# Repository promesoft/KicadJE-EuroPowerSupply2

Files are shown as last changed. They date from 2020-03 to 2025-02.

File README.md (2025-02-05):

# KicadJE-EuroPowerSupply2
4HP PSU faceplate with 80x100mm PSU + PDU board. Faceplate input from a laptop PSU (19V) and may be daisychained to the next Eurorack unit.

Please note this method of making +- 12v could be impaired by the laptop PSU ground connection. Some PSU's connect earth to GND (sleeve) which will be connected to -12v and not GND in this circuit. If the laptop PSU only has 2 pins or the 3rd pin is not connected to the sleeve of 19v supply there will be no issues with this design.

There is a third version that does not rely on a laptop supply in the making (2025 Q1)

# Vital Components

# Status - mounted in rack
## Initial 
| Stage  | Detail | Status |
| --- | --- | --- |
| create material  | sch | done |
| | pcb | done |
| | gerber | done |
| production  | | done |
|  | produced | done |
|  | delivered | done |
## Preliminary validation
| Test  | Detail | Status |
| --- | --- | --- |
| Initial Inspection | | good alignment w panel - panel: pwr holes 2 mm too small |
| Initial Technical Test |  | OL LED's lighting up without load - probably due to the extra resistance of the polyfuse |
| Initial Technical Test |  | OL LED's ok with 2k2 but unsure of how they work now - 3k9 is ok without load but makes a bit of a light at a few XX mA |
| Initial Technical Test |  | input fuse experienced a few problems after shoring the input of the DC-DC by mistake
| Initial Product Test |  | ok - Powers the uP DAC nicely|

## Secondary validation
| Test  | Detail | Status |
| --- | --- |--- |
| Product Test |  | |
| Product Test |  | |
| Quality |  | |
| Quality | | |
| Long Term Product Test |  | Working for a year without stability issues | 
|  | | Bridge recitifier gets warm/hot |
| Power Draw | up to 750mA 19V | 

## Errata
### Errata - 
Holes for Pwr in and out are 2mm too small in face plate

Place DCDC input further away from electronics on the backside - risky location

## Issues and Notes
### Front
There is just enough room on the front PCB to add a JST header for power feed to baseboard.

### Regulation
Input cap C101 = 470uF/50V

Reg input cap C207 - 470uF/16V for 5V

Reg input cap C204 C212 - 100uF/35V for +-12V

Reg output cap C206 C209 C214 - 470uF/16V for all

### Output
Only half the headers has decoupling caps

Place +/-15v header away from heatsink area.

### Overload Circuit
Not easy to measure the OL circuit as it is VERY close to the DC-DC input  
Add current limiter on input and consider changing from OL to currentlimier with limit indication  
OL LED's ok with 2k2 but unsure of how they work now - 3k9 is ok without load but makes a bit of a light at a few XX mA  

### Extensions
Consider calc initial regulator stage as Capacitor multiplier and add small signal BJT in darlington config.
 - https://www.google.com/search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

# Pictures
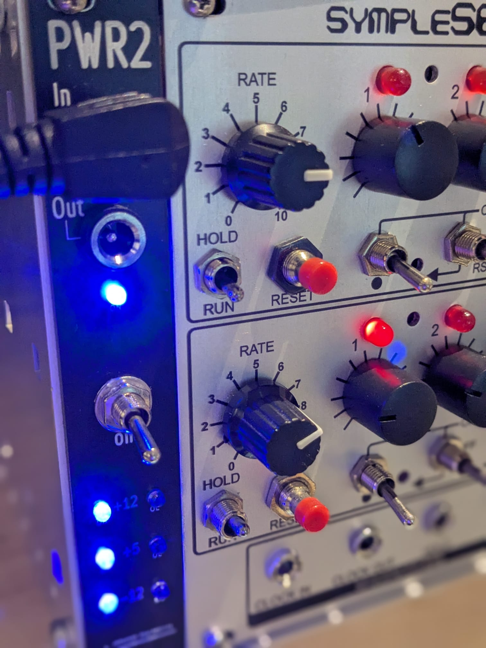
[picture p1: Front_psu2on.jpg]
Front Picture

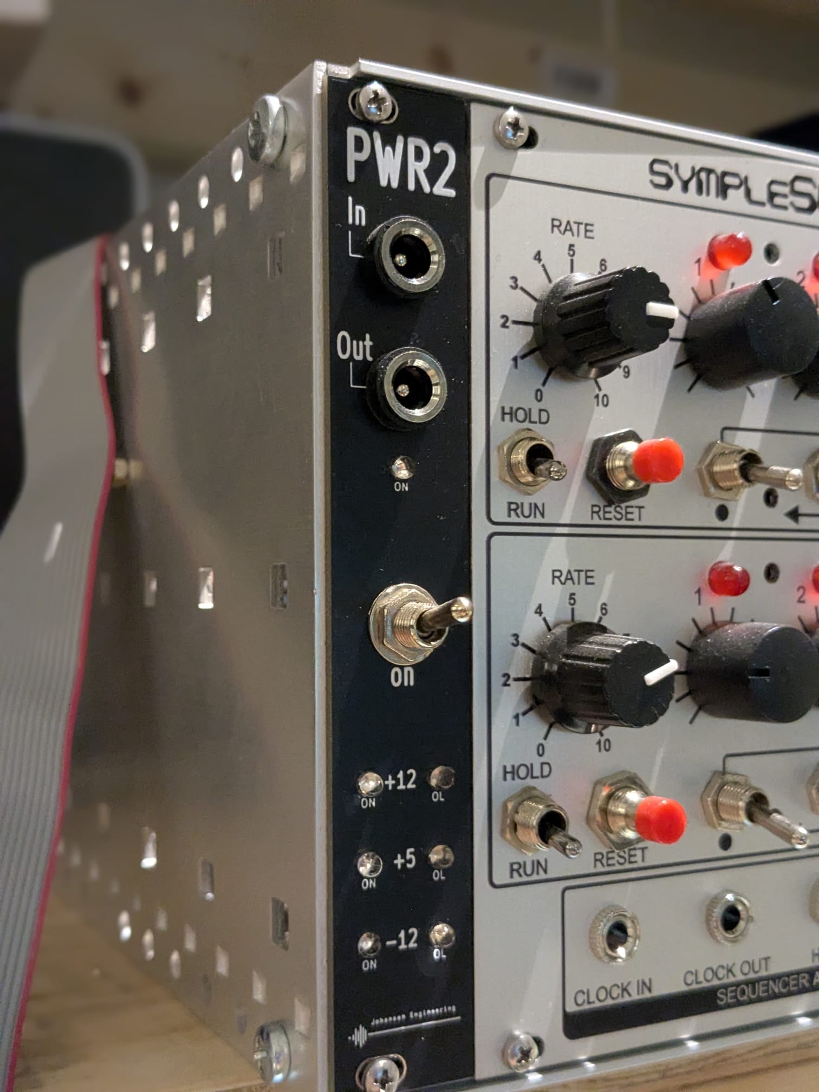
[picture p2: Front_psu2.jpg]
Front Picture

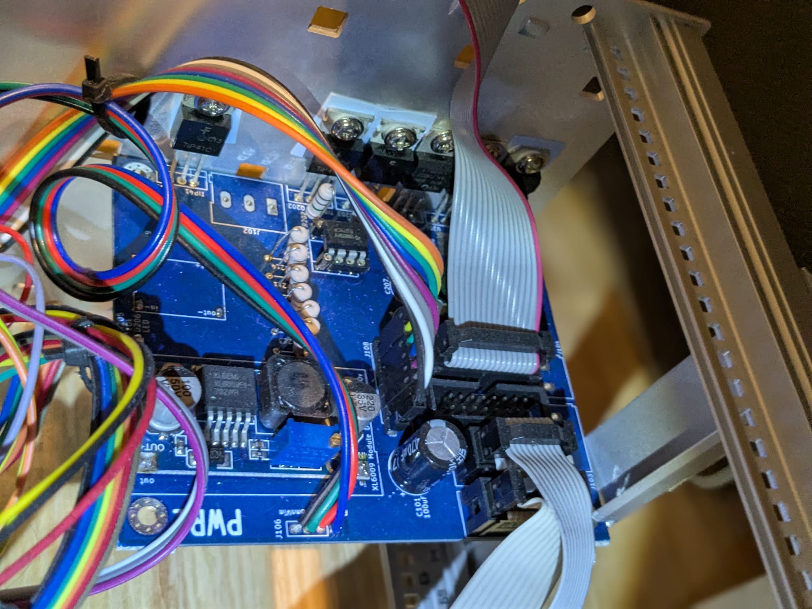
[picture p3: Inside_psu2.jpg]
Inside Picture

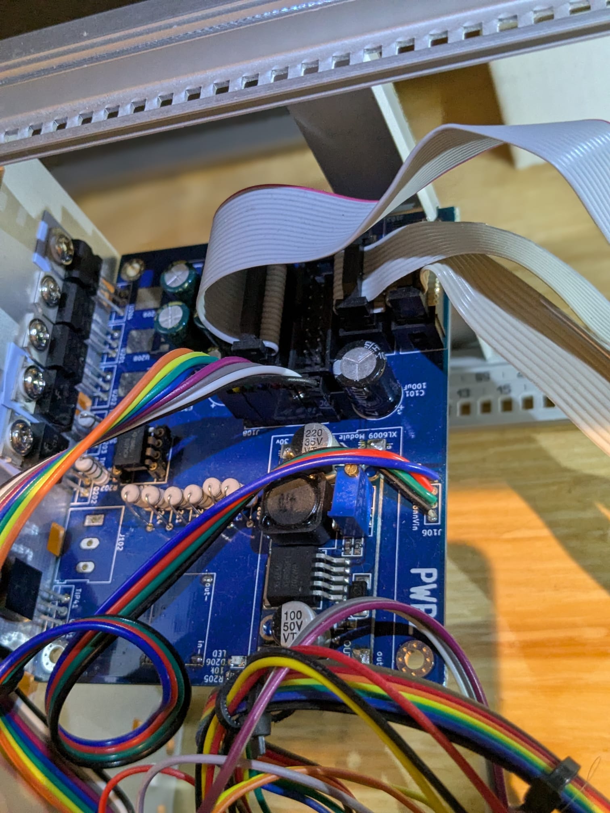
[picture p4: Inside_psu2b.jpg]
Inside Picture

## Rendered
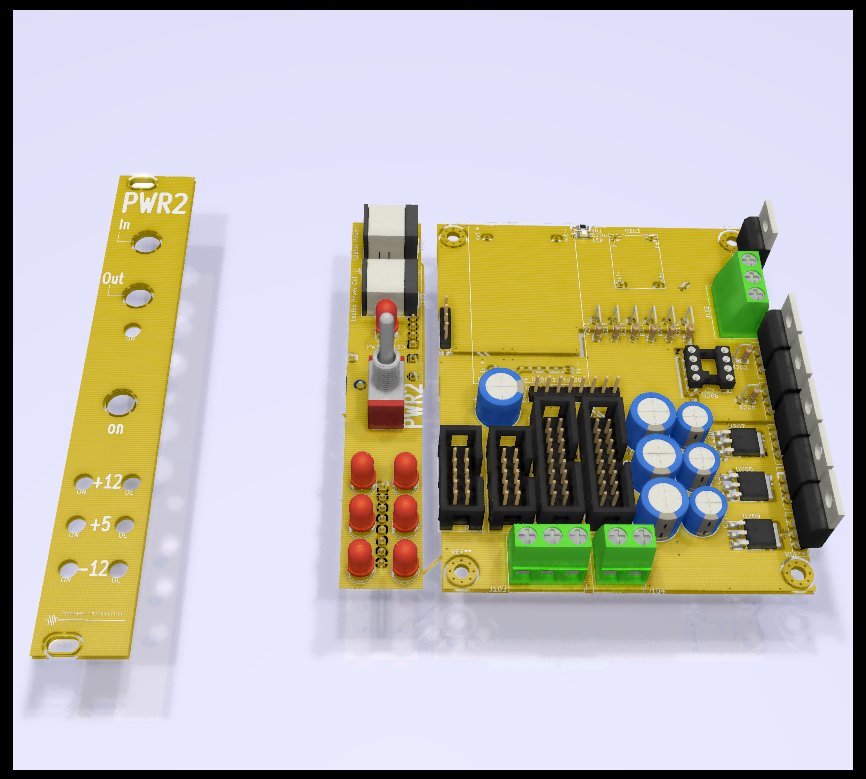
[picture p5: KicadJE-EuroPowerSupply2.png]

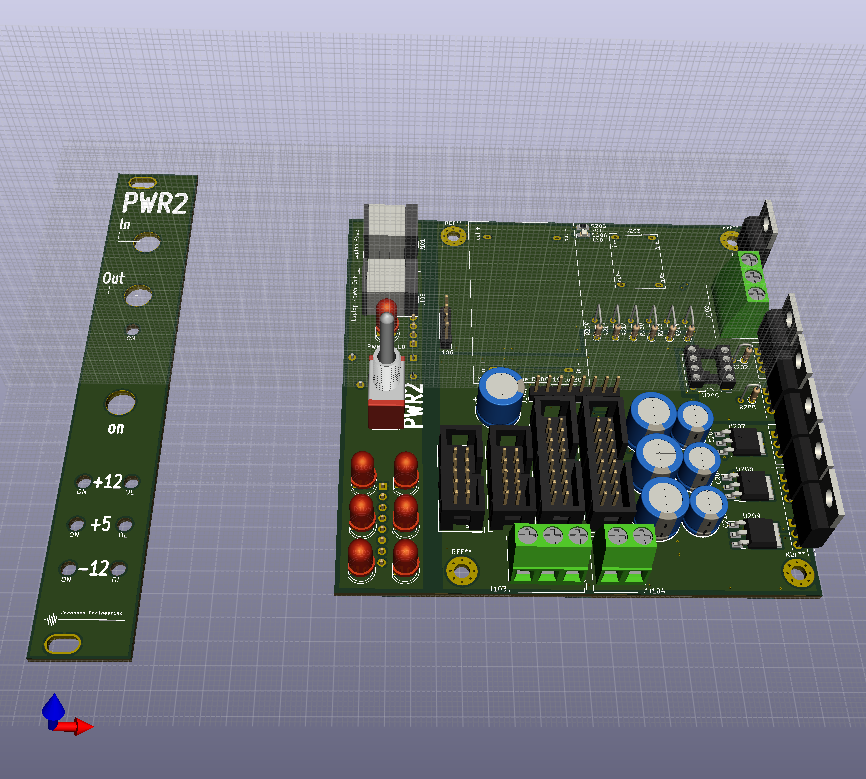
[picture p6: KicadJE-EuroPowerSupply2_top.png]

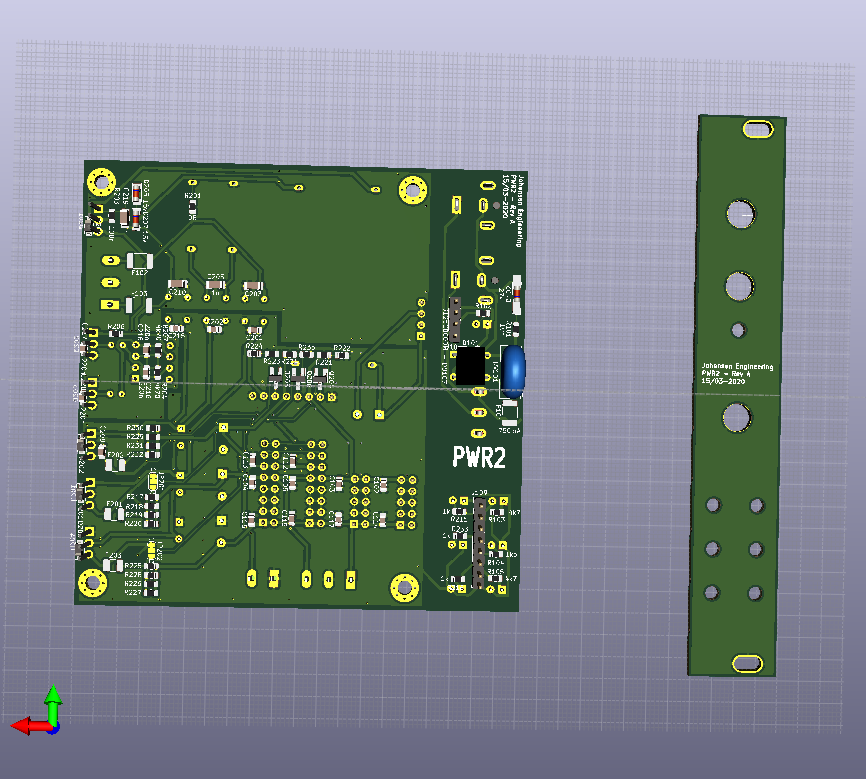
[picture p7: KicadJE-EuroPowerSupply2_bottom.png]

# Schematic
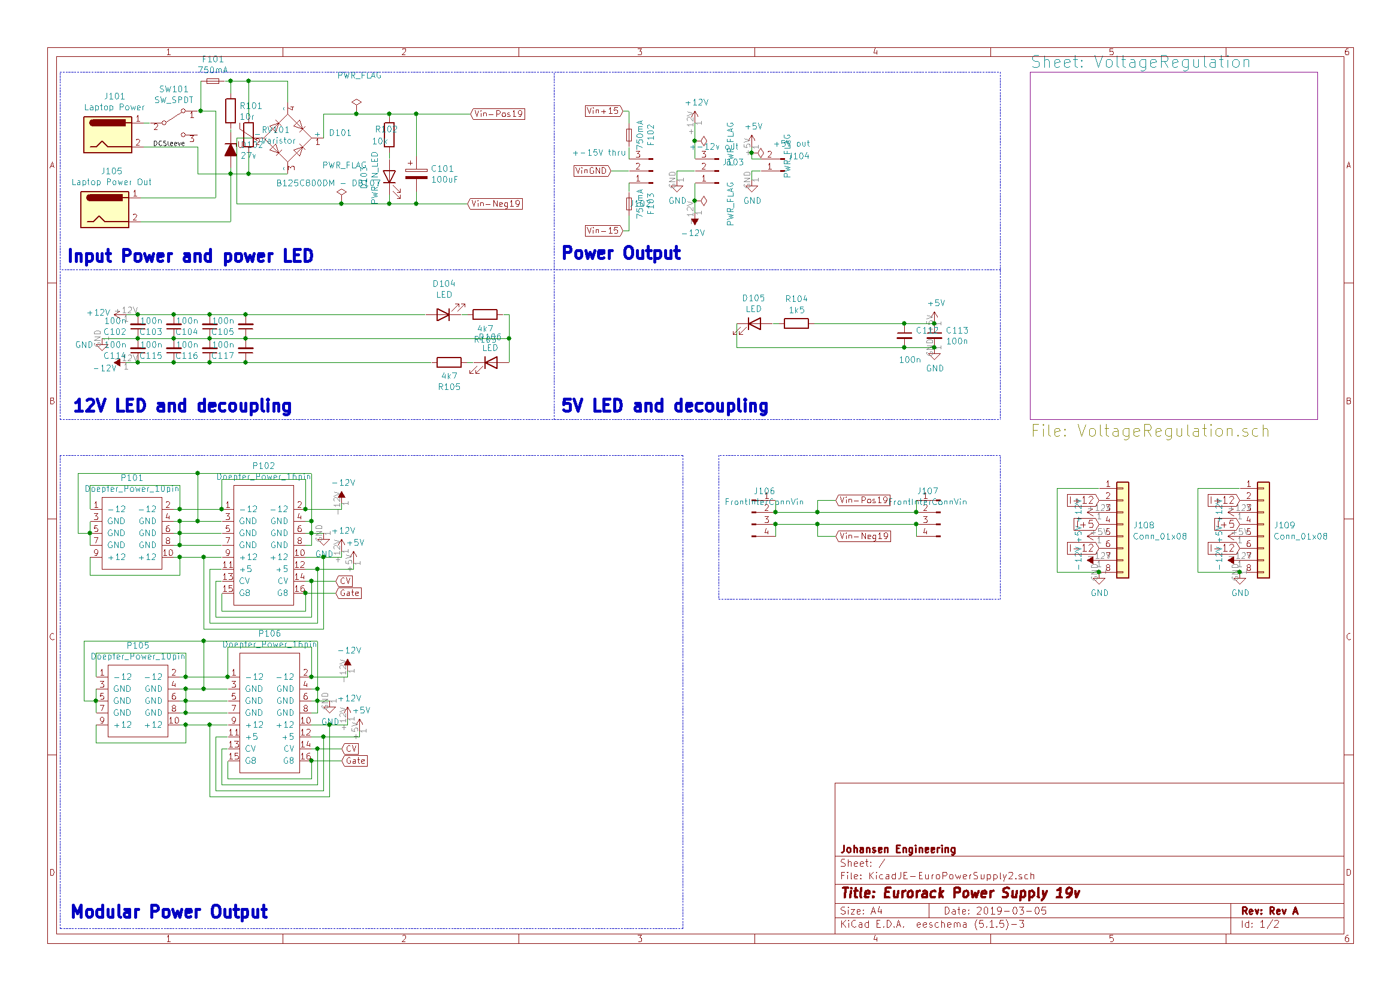
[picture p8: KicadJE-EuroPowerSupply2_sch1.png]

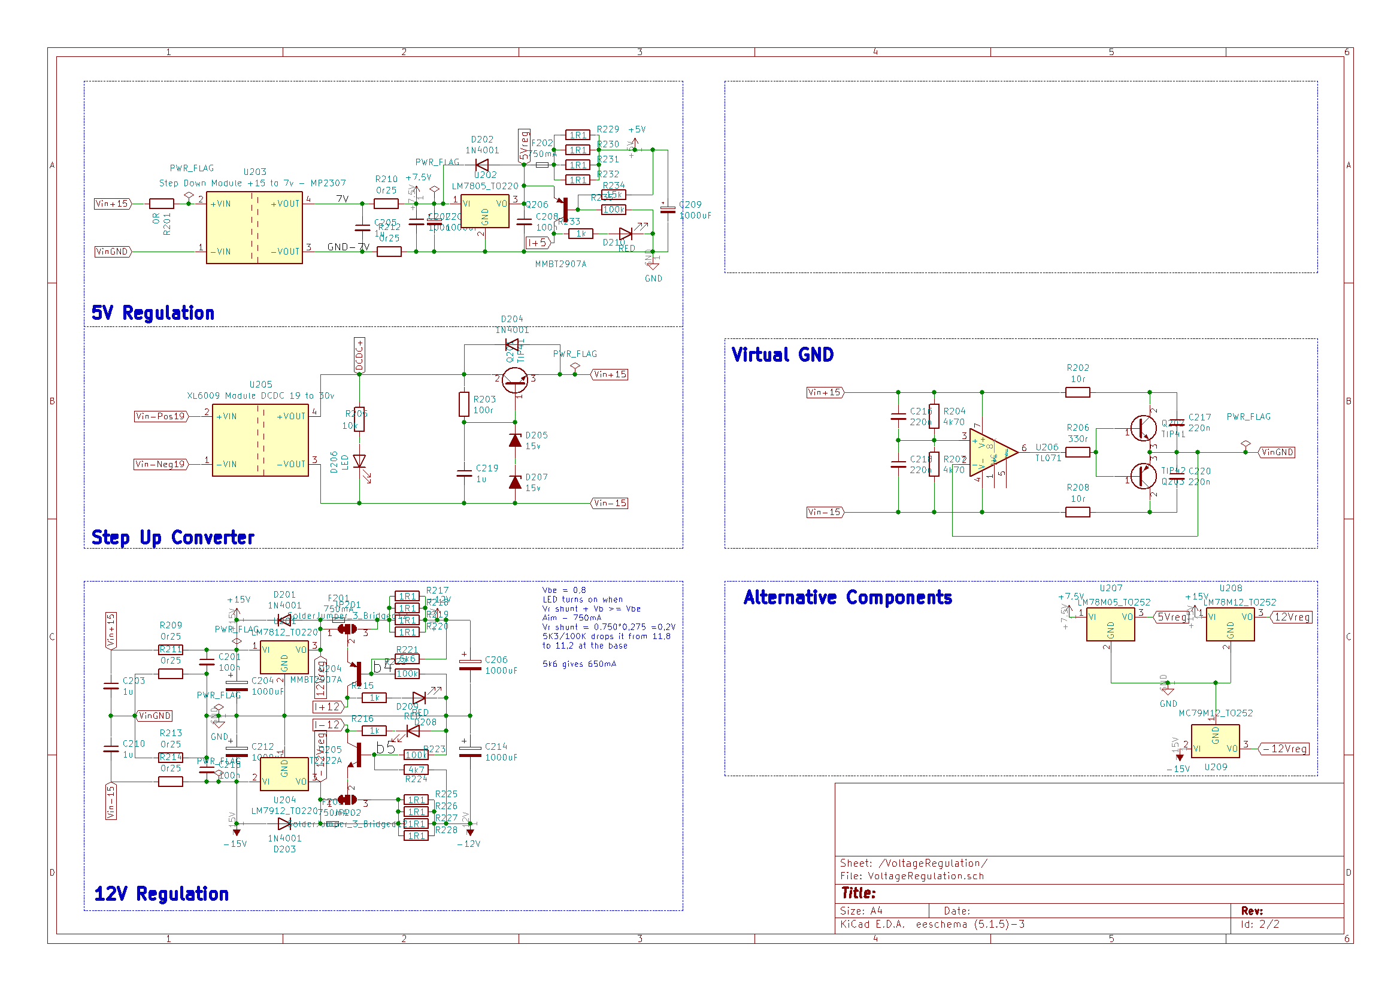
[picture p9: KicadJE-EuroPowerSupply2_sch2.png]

## Prototype

# Inspiration
## Rev 1
https://github.com/promesoft/KicadJE-EuroPowerSupply

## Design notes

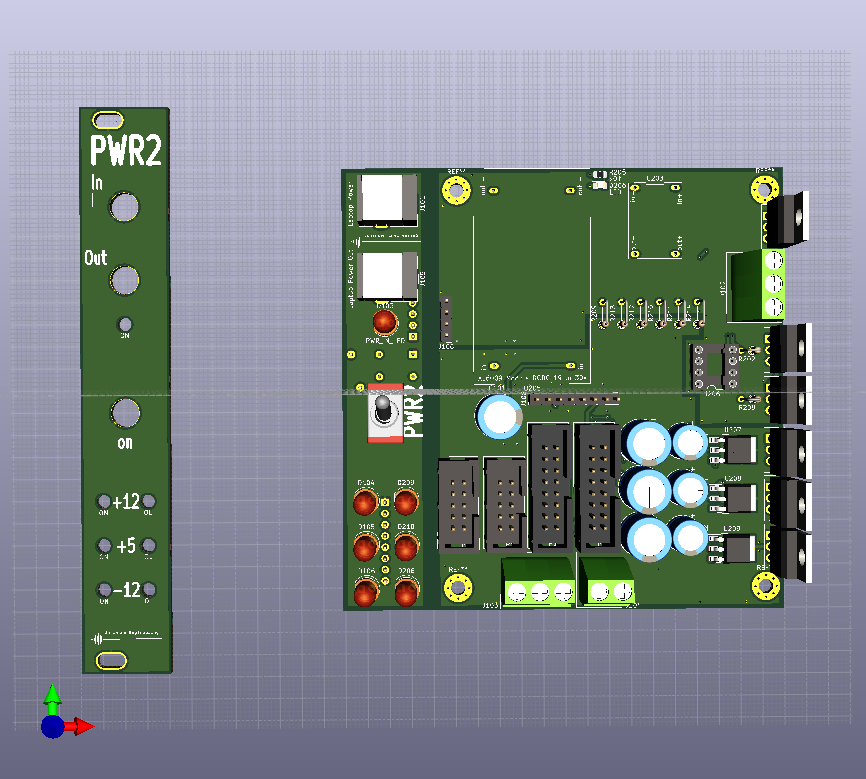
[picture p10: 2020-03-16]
KicadJE-EuroPowerSupply2_top2.png

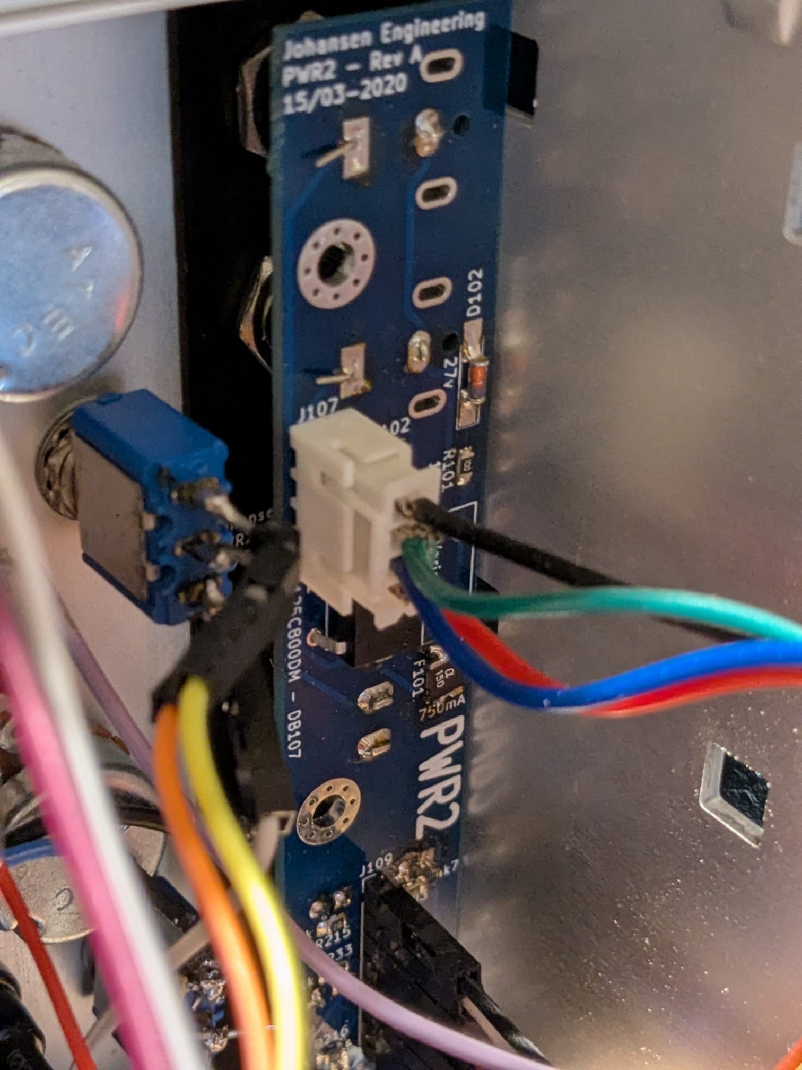
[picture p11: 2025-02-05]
Front_psu2on_back.jpg

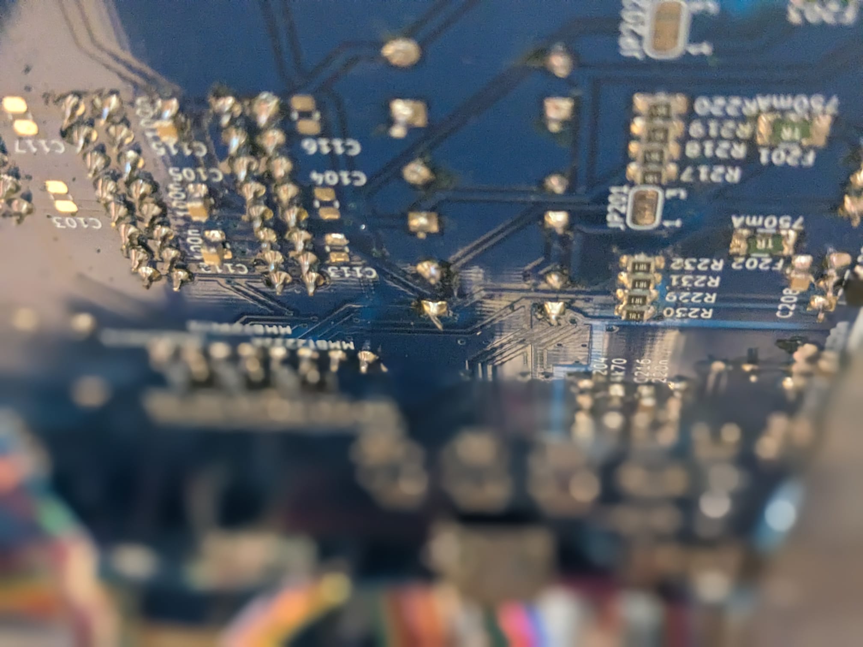
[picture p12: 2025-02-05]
Inside_psu2_bottom.jpg

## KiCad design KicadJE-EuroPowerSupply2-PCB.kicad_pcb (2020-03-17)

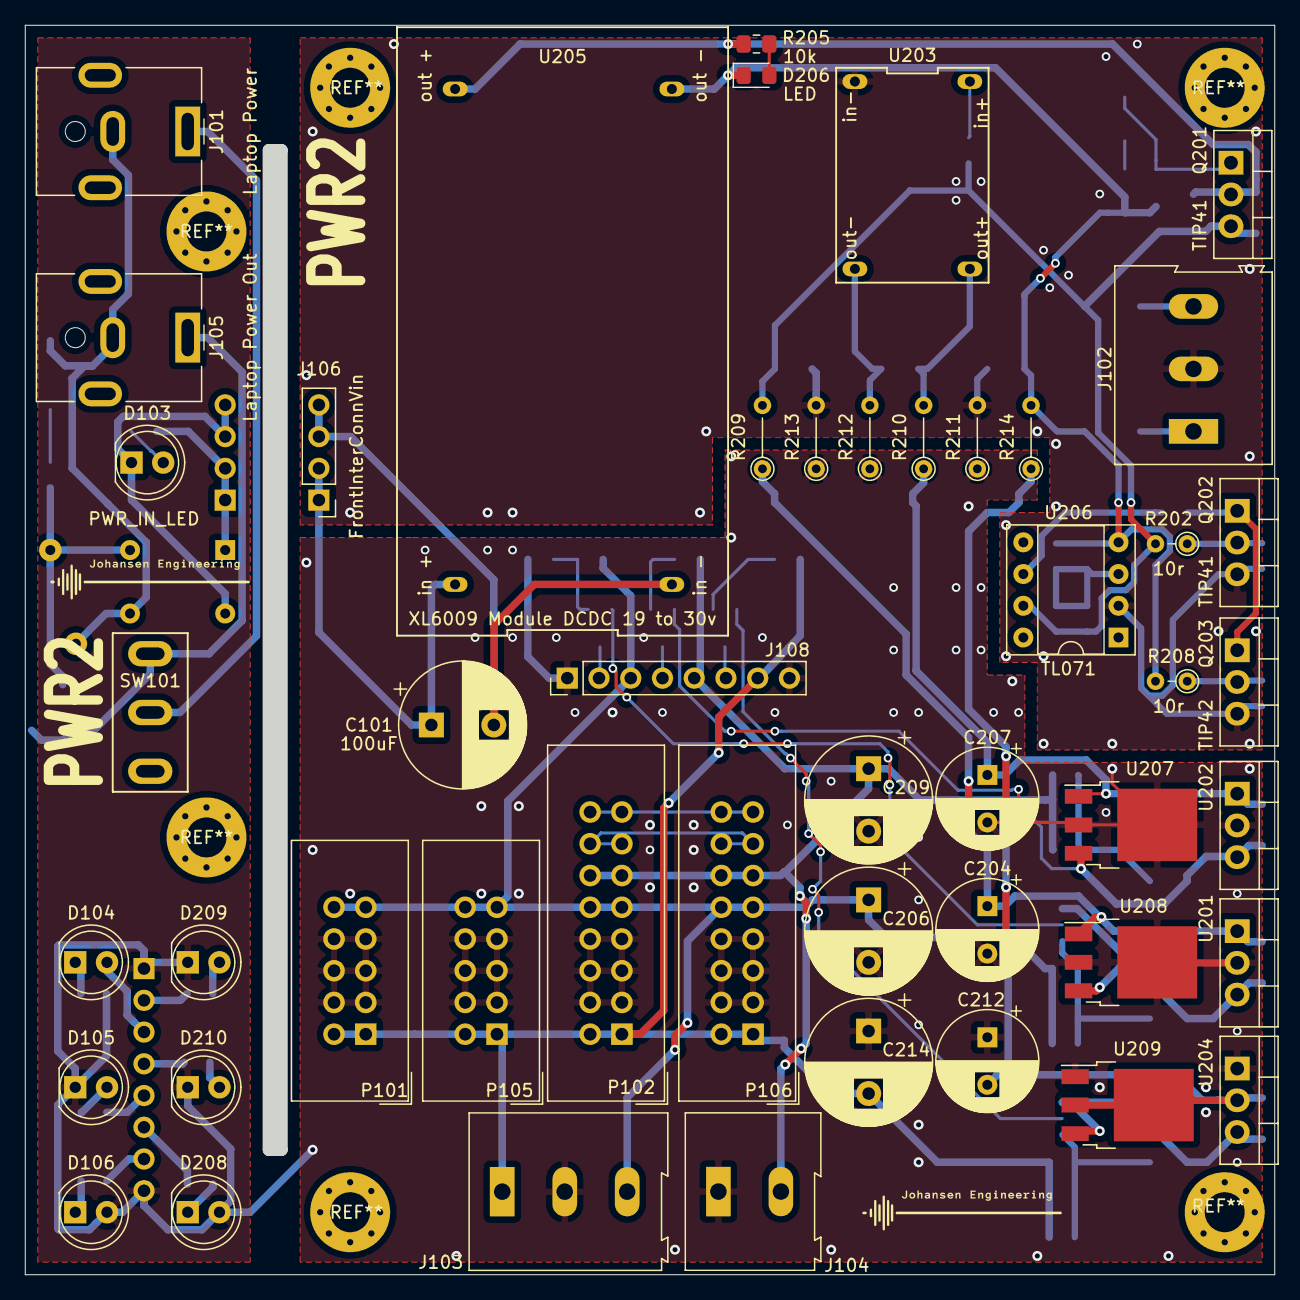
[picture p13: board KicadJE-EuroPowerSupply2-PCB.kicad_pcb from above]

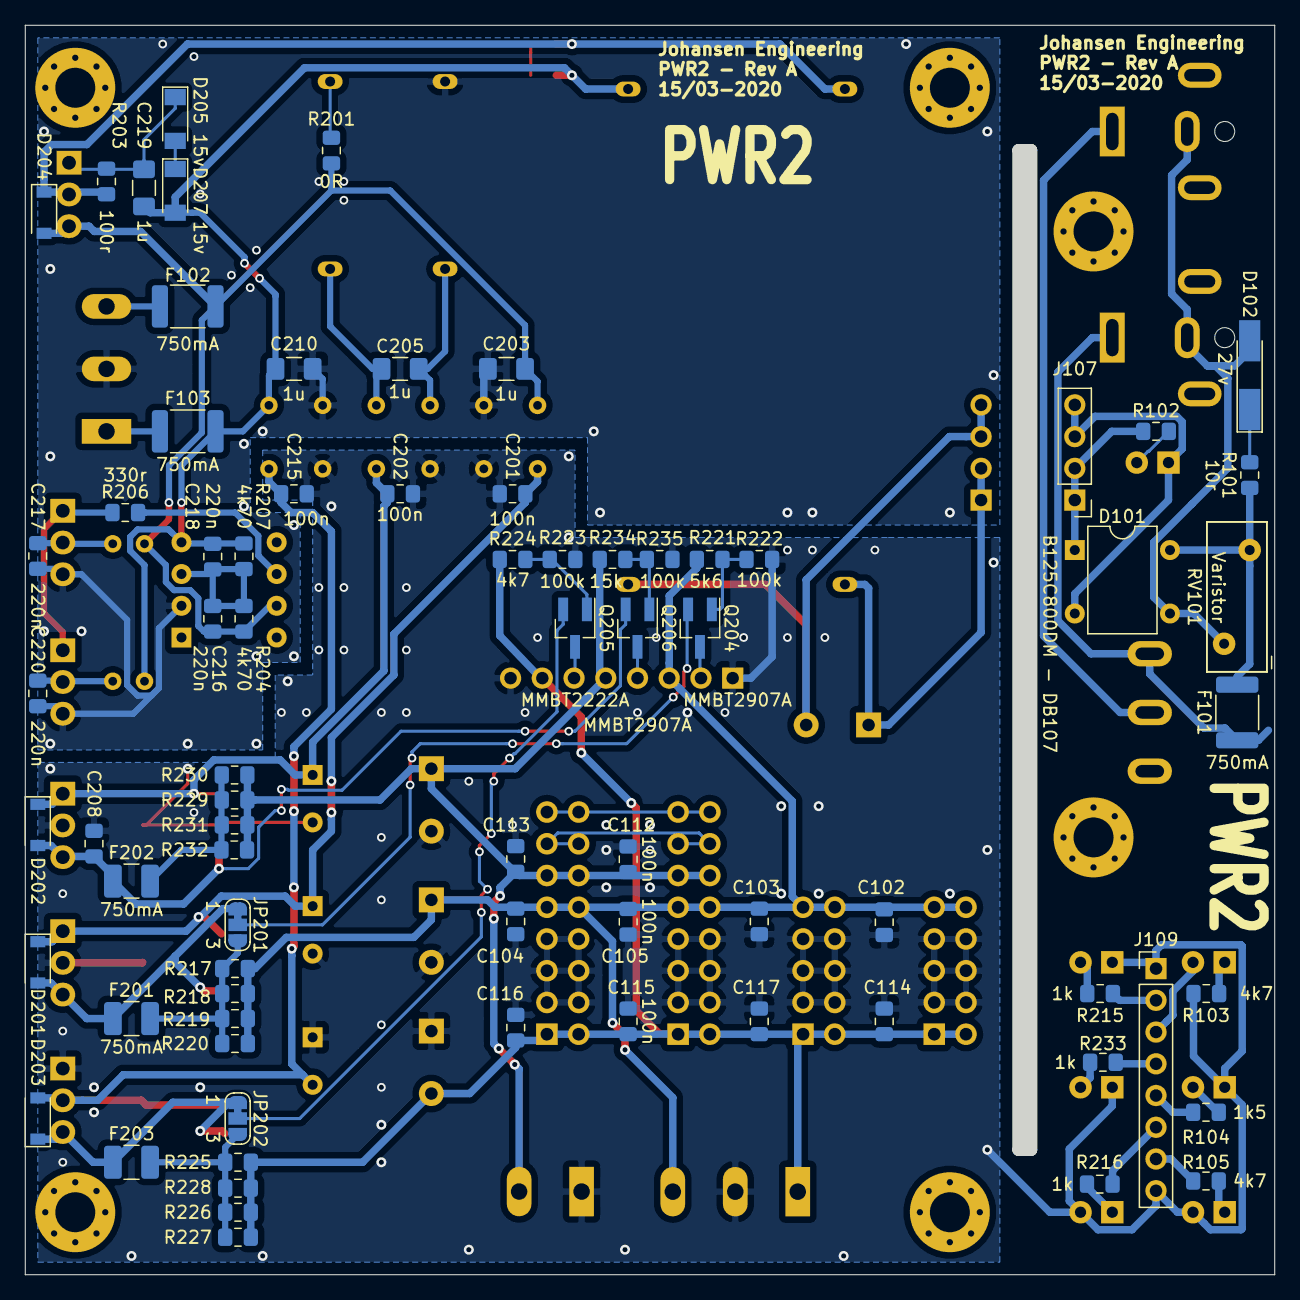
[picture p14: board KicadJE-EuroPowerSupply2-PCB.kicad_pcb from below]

Board: 2 copper layers, 100.0 x 100.0 mm, 123 parts (75 on the bottom side), 54 nets.

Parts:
C101: 100uF; CP_Radial_D10.0mm_P5.00mm
C102, C103, C104, C105, C112, C113, C114, C115, C116, C117, C201, C202, C208, C215: 100n; C_0805_2012Metric_Pad1.15x1.40mm_HandSolder
C203, C205, C210, C219: 1u; C_1206_3216Metric_Pad1.42x1.75mm_HandSolder
C204, C207, C212: 1000uF; CP_Radial_D8.0mm_P3.80mm
C206, C209, C214: 1000uF; CP_Radial_D10.0mm_P5.00mm
C216, C217, C218, C220: 220n; C_0805_2012Metric_Pad1.15x1.40mm_HandSolder
D101: B125C800DM - DB107; Diode_Bridge_DIP-4_W7.62mm_P5.08mm
D102: 27v; D_MiniMELF_Handsoldering
D103: PWR_IN_LED; LED_D5.0mm
D104, D105, D106: LED; LED_D5.0mm
D201, D202, D203, D204: 1N4001; D_SOD-123
D205, D207: 15v; D_MiniMELF
D206: LED; LED_0805_2012Metric_Pad1.15x1.40mm_HandSolder
D208, D209, D210: RED; LED_D5.0mm
F101, F102, F103: 750mA; Fuse_1812_4532Metric_Pad1.30x3.40mm_HandSolder
F201, F202, F203: 750mA; Fuse_1210_3225Metric_Pad1.42x2.65mm_HandSolder
J101: Laptop Power; BarrelJack_CUI_PJ-063AH_Horizontal
J102: +-15V thru; TerminalBlock_Altech_AK300-3_P5.00mm
J103: +-12v out; TerminalBlock_Altech_AK300-3_P5.00mm
J104: +5V out; TerminalBlock_Altech_AK300-2_P5.00mm
J105: Laptop Power Out; BarrelJack_CUI_PJ-063AH_Horizontal
J106, J107: FrontInterConnVin; PinHeader_1x04_P2.54mm_Vertical
J108, J109: Conn_01x08; PinHeader_1x08_P2.54mm_Vertical
JP201, JP202: SolderJumper_3_Bridged12; SolderJumper-3_P1.3mm_Bridged12_RoundedPad1.0x1.5mm_NumberL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
P101, P105: Doepfer_Power_10pin; IDC-Header_2x05_Pitch2.54mm_Straight
P102, P106: Doepfer_Power_16pin; IDC-Header_2x08_Pitch2.54mm_Straight
Q201, Q202: TIP41; TO-220-3_Vertical
Q203: TIP42; TO-220-3_Vertical
Q204, Q206: MMBT2907A; SOT-23_Handsoldering
Q205: MMBT2222A; SOT-23_Handsoldering
R101: 10r; R_0805_2012Metric_Pad1.15x1.40mm_HandSolder
R102, R205: 10k; R_0805_2012Metric_Pad1.15x1.40mm_HandSolder
R103, R105, R224: 4k7; R_0805_2012Metric_Pad1.15x1.40mm_HandSolder
R104: 1k5; R_0805_2012Metric_Pad1.15x1.40mm_HandSolder
R201: 0R; R_0805_2012Metric_Pad1.15x1.40mm_HandSolder
R202, R208: 10r; R_Axial_DIN0204_L3.6mm_D1.6mm_P2.54mm_Vertical
R203: 100r; R_0805_2012Metric_Pad1.15x1.40mm_HandSolder
R204, R207: 4k70; R_0805_2012Metric_Pad1.15x1.40mm_HandSolder
R206: 330r; R_0805_2012Metric_Pad1.15x1.40mm_HandSolder
R209, R210, R211, R212, R213, R214: 0r25; R_Axial_DIN0204_L3.6mm_D1.6mm_P5.08mm_Vertical
R215, R216, R233: 1k; R_0805_2012Metric_Pad1.15x1.40mm_HandSolder
R217, R218, R219, R220, R225, R226, R227, R228, R229, R230, R231, R232: 1R1; R_0805_2012Metric_Pad1.15x1.40mm_HandSolder
R221: 5k6; R_0805_2012Metric_Pad1.15x1.40mm_HandSolder
R222, R223, R235: 100k; R_0805_2012Metric_Pad1.15x1.40mm_HandSolder
R234: 15k; R_0805_2012Metric_Pad1.15x1.40mm_HandSolder
RV101: Varistor; RV_Disc_D12mm_W4.8mm_P7.5mm
SW101: SW_SPDT; SP1MS1
U201: LM7812_TO220; TO-220-3_Vertical
U202: LM7805_TO220; TO-220-3_Vertical
U203: Step Down Module +15 to 7v - MP2307; MP2307 DCDC module
U204: LM7912_TO220; TO-220-3_Vertical
U205: XL6009 Module DCDC 19 to 30v; XL6009-DCDC-Module
U206: TL071; DIP-8_W7.62mm_Socket
U207: LM78M05_TO252; TO-252-3_TabPin2
U208: LM78M12_TO252; TO-252-3_TabPin2
U209: MC79M12_TO252; TO-252-3_TabPin2

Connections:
5Vreg: C208.1, D202.2, F202.1, Q206.2, U202.3, U207.3
12Vreg: D201.2, F201.1, JP201.1, U201.3, U208.3
+5V: C112.1, C113.1, C209.1, J104.2, J108.5, J109.5, P102.11, P102.12, P106.11, P106.12, R104.1, R229.1, R230.1, R231.1, R232.1, R234.2
+7.5V: C202.1, C207.1, D202.1, R210.1, U202.1, U207.1
+12V: C102.2, C103.2, C104.2, C105.2, C206.1, D104.2, J103.3, J108.3, J109.3, P101.9, P101.10, P102.9, P102.10, P105.9, P105.10, P106.9, P106.10, R217.1, R218.1, R219.1, R220.1, R221.2
+15V: C201.1, C204.1, D201.1, R209.1, U201.1, U208.1
-12V: C114.1, C115.1, C116.1, C117.1, C214.2, J103.1, J108.7, J109.7, P101.1, P101.2, P102.1, P102.2, P105.1, P105.2, P106.1, P106.2, R105.1, R224.1, R225.1, R226.1, R227.1, R228.1
-12Vreg: D203.1, F203.1, JP202.1, U204.3, U209.3
-15V: C212.2, C215.2, D203.2, R214.1, U204.2, U209.2
/DCSleeve: D101.3, D102.2, J101.2, J105.2, RV101.2
/VoltageRegulation/7V: C205.1, R210.2, U203.4
/VoltageRegulation/GND-7V: C205.2, R212.2, U203.3
/VoltageRegulation/b4: Q204.1, R221.1, R222.1
/VoltageRegulation/b5: Q205.1, R223.2, R224.2
CV: P102.13, P102.14, P106.13, P106.14
DCDC+: D204.1, Q201.2, R203.1, R205.1, U205.4
GND: C102.1, C103.1, C104.1, C105.1, C112.2, C113.2, C114.2, C115.2, C116.2, C117.2, C201.2, C202.2, C204.2, C206.2, C207.2, C208.2, C209.2, C212.1, C214.1, C215.1, D105.1, D106.2, D208.2, D209.1, D210.1, J103.2, J104.1, J108.1, J108.8, J109.1, J109.8, P101.3, P101.4, P101.5, P101.6, P101.7, P101.8, P102.3, P102.4, P102.5, P102.6, P102.7, P102.8, P105.3, P105.4, P105.5, P105.6, P105.7, P105.8, P106.3, P106.4, P106.5, P106.6, P106.7, P106.8, R103.1, R211.1, R212.1, R213.1, R222.2, R223.1, R235.2, U201.2, U202.2, U204.1, U207.2, U208.2, U209.1
Gate: P102.15, P102.16, P106.15, P106.16
I+5: J108.4, J109.4, Q206.3, R233.1
I+12: J108.2, J109.2, Q204.3, R215.1
I-12: J108.6, J109.6, Q205.3, R216.1
unnamed: C216.2, C218.1, R204.2, R207.1, U206.3
unnamed: C217.1, Q202.2, R202.1
unnamed: C219.1, D205.1, Q201.1, R203.2
unnamed: C220.2, Q203.2, R208.1
unnamed: D101.4, F101.2, R101.1, RV101.1
unnamed: D102.1, R101.2
unnamed: D103.2, R102.2
unnamed: D104.1, R103.2
unnamed: D105.2, R104.2
unnamed: D106.1, R105.2
unnamed: D205.2, D207.1
unnamed: D206.2, R205.2
unnamed: D208.1, R216.2
unnamed: D209.2, R215.2
unnamed: D210.2, R233.2
unnamed: F101.1, J105.1, SW101.1
unnamed: F102.2, J102.3
unnamed: F103.1, J102.1
unnamed: F201.2, JP201.3, R217.2, R218.2, R219.2, R220.2
unnamed: F202.2, R229.2, R230.2, R231.2, R232.2
unnamed: F203.2, JP202.3, R225.2, R226.2, R227.2, R228.2
unnamed: J101.1, SW101.2
unnamed: JP201.2, Q204.2
unnamed: JP202.2, Q205.2
unnamed: Q202.1, Q203.1, R206.1
unnamed: Q206.1, R234.1, R235.1
unnamed: R201.1, U203.2
unnamed: R206.2, U206.6
Vin+15: C203.1, C216.1, D204.2, F102.1, Q201.3, R201.2, R202.2, R204.1, R209.2, U206.7
Vin-15: C210.2, C218.2, C219.2, D206.1, D207.2, F103.2, R207.2, R208.2, R214.2, U205.3, U206.4
Vin-Neg19: C101.2, D101.2, D103.1, J106.3, J106.4, J107.3, J107.4, U205.1
Vin-Pos19: C101.1, D101.1, J106.1, J106.2, J107.1, J107.2, R102.1, U205.2
VinGND: C203.2, C210.1, C217.2, C220.1, J102.2, Q202.3, Q203.3, R211.2, R213.2, U203.1, U206.2

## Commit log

2020-03-12 init from old projects
    [KicadJE-EuroPowerSupply2.kicad_pcb, KicadJE-EuroPowerSupply2.sch, VoltageRegulation.sch]
2020-03-15 Init 750mA indicator
    [KicadJE-EuroPowerSupply2.sch, VoltageRegulation.sch]
2020-03-15 5V current sensor
    [VoltageRegulation.sch]
2020-03-15 Jumper before/after fuse
    [VoltageRegulation.sch]
2020-03-15 placing first components
    [KicadJE-EuroPowerSupply2.kicad_pcb, KicadJE-EuroPowerSupply2.sch, VoltageRegulation.sch]
2020-03-15 interboard connector
    [KicadJE-EuroPowerSupply2.sch, VoltageRegulation.sch]
2020-03-15 PCB adjustments
    [KicadJE-EuroPowerSupply2.kicad_pcb]
2020-03-15 Almost completely placed
    [KicadJE-EuroPowerSupply2.kicad_pcb, KicadJE-EuroPowerSupply2.sch]
2020-03-16 Update KicadJE-EuroPowerSupply2.kicad_pcb
    Components placed
    [KicadJE-EuroPowerSupply2.kicad_pcb]
2020-03-16 Board setup - power lines
    [KicadJE-EuroPowerSupply2.kicad_pcb]
2020-03-16 Update KicadJE-EuroPowerSupply2.kicad_pcb
    Wired initially
    [KicadJE-EuroPowerSupply2.kicad_pcb]
2020-03-17 Update KicadJE-EuroPowerSupply2.kicad_pcb
    DRC + Labels
    [KicadJE-EuroPowerSupply2.kicad_pcb]
2020-03-17 Complete Gerber Rev A
    [KicadJE-EuroPowerSupply2-B_Cu.gbr, KicadJE-EuroPowerSupply2-B_Mask.gbr, KicadJE-EuroPowerSupply2-B_Paste.gbr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]
2020-03-17 Faceplate Gerber
    [KicadJE-EuroPowerSupply2-Faceplate-B_Cu.gbr, KicadJE-EuroPowerSupply2-Faceplate-B_Mask.gbr, KicadJE-EuroPowerSupply2-Faceplate-B_Paste.gbr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]
2020-03-17 PCB Gerber
    Gerber
    [KicadJE-EuroPowerSupply2-PCB-B_Cu.gbr, KicadJE-EuroPowerSupply2-PCB-B_Mask.gbr, KicadJE-EuroPowerSupply2-PCB-B_Paste.gbr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]
2020-03-17 Gerber update
    [KicadJE-EuroPowerSupply2-Faceplate-B_Cu.gbr, KicadJE-EuroPowerSupply2-Faceplate-B_Mask.gbr, KicadJE-EuroPowerSupply2-Faceplate-B_Paste.gbr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]
2020-04-27 version upd
    [KicadJE-EuroPowerSupply2-PCB.sch]
2021-04-22 Update Kicad version
2025-01-16 Update README.md
    Please note this method of making +- 12v could be impaired by the laptop PSU ground connection. Some PSU's connect earth to GND (sleeve) which will be connected to -12v and not GND in this circuit.
2025-02-04 Update README.md
    Schematic on readme
2025-02-05 Real life pictures
    [VoltageRegulation.sch]
